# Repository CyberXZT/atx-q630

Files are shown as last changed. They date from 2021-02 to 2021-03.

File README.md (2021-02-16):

# ATX - Quadra 630 PSU Conversion Kit
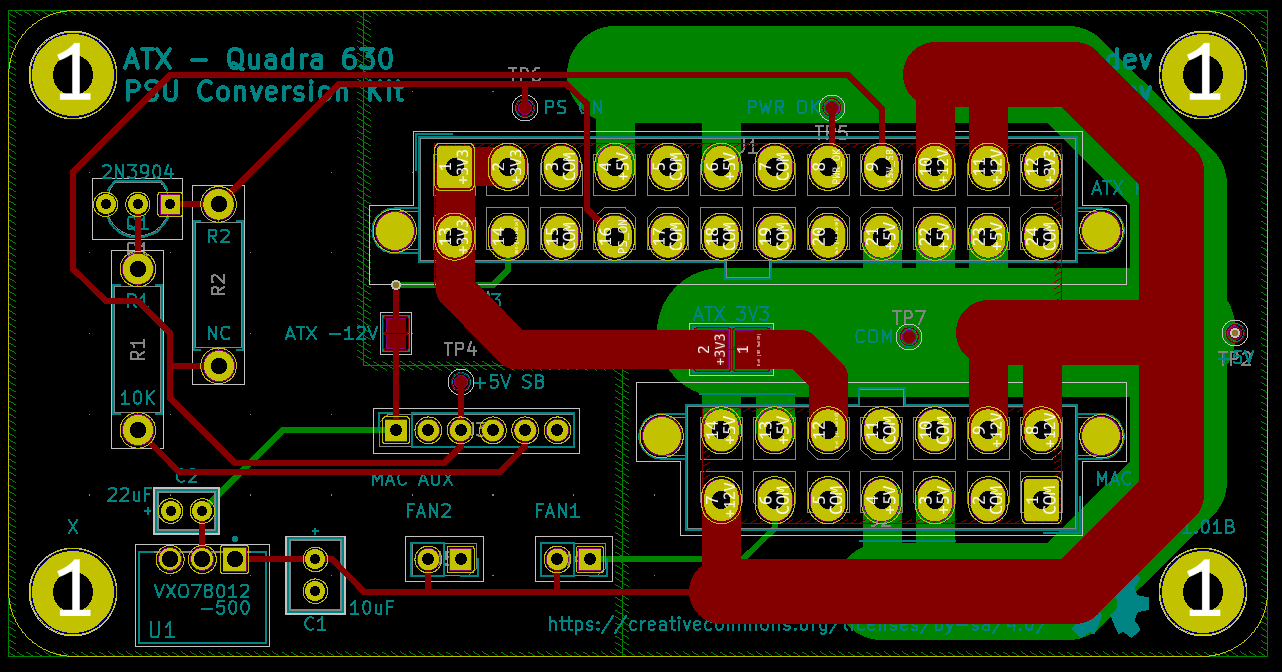
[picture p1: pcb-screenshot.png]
PCB Screenshot


This is an ATX/Quadra 630 PSU conversion PCB that I designed a while ago and
never got around to uploading.

[BOM](bom.csv)

**I am not an electrical engineer. I take no responsibility for any damage
these designs may cause. Use these designs with extreme caution.**

## Quick Notes
* R2 is unused.
* U1, C1, and C2 provide the -12V rail. If your PSU provides -12V, do not
populate these. Instead, bridge the "ATX -12V" jumper.
* 3.3V is not connected by default. The PSU in the original Quadra 630 PSU
uses this wire for ground. While the motherboards I tested did not actually
connect this wire, I have left it not connected by default. If you need 3.3V,
bridge the "ATX 3V3" jumper.
* I can't a good connector for the 6-pin "MAC-AUX" connector. The BOM
references the best fitting part although the smaller wall has to be cut in
order for the connector to fit. 
* PCB was designed with 2oz copper in mind.

## License and Copyright

Copyright &copy; Dean Winger 2021

This work is licensed under the Creative Commons
Attribution-ShareAlike 4.0 International License. To view a copy of
this license, visit http://creativecommons.org/licenses/by-sa/4.0/ or
send a letter to Creative Commons, PO Box 1866, Mountain View, CA
94042, USA.

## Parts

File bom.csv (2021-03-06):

Manufacturer Part Number | Manufacturer | Digi-Key Part Number | Customer Reference | Reference Designator | Packaging | Part Status | Quantity | Unit Price | Extended Price | Quantity Available | Mfg Std Lead Time | Description | RoHS Status | Lead Free Status | REACH Status
0015247141 | Molex | 23-0015247141-ND |  | J2 | Tray | Active | 1 | 3.18000 | $3.18 | 1019 | 18 Weeks | CONN RCPT 14POS 0.165 TIN PCB | ROHS3 Compliant | Lead free | REACH Unaffected
0460152403 | Molex | WM6198-ND |  | J1 | Tray | Active | 1 | 3.91000 | $3.91 | 734 | 7 Weeks | CONN HEADER VERT 24POS 4.2MM | ROHS3 Compliant | Lead free | REACH Unaffected
SWR25X-NRTC-S02-ST-BA | Sullins Connector Solutions | S9407-ND |  | J4,J5 | Bulk | Active | 2 | 0.12000 | $0.24 | 13375 | 5 Weeks | CONN HEADER VERT 2POS 2.54MM | ROHS3 Compliant | Lead free | REACH Unaffected
ROX05SJ10K | TE Connectivity Passive Product | A142728CT-ND |  | R1 | Cut Tape (CT) | Active | 1 | 0.18000 | $0.18 | 9324 | 18 Weeks | RES 1/2W SM M/OX 5% 10K | RoHS Compliant | Lead free | Not Available
FG14X5R1E226MRT06 | TDK Corporation | 445-173129-1-ND |  | C2 | Cut Tape (CT) | Active | 1 | 0.72000 | $0.72 | 2676 | 24 Weeks | CAP CER 22UF 25V X5R RADIAL | ROHS3 Compliant | Lead free | REACH Unaffected
FG11X7S1H106KRT06 | TDK Corporation | 445-180817-1-ND |  | C1 | Cut Tape (CT) | Active | 1 | 1.09000 | $1.09 | 2515 | 24 Weeks | CAP CER 10UF 50V X7S RADIAL | ROHS3 Compliant | Lead free | REACH Unaffected
VXO78012-500 | CUI Inc. | 102-4250-ND |  | U1 | Tray | Active | 1 | 2.36000 | $2.36 | 762 | 12 Weeks | DC DC CONVERTER 12V OR -12V 6W | RoHS Compliant | Lead free | Not Available
828548-6 | TE Connectivity AMP Connectors | A129104-ND |  | J3 | Bulk | Active | 1 | 0.47000 | $0.47 | 7923 | 21 Weeks | CONN HEADER VERT 6POS 2.54MM | RoHS Compliant | Lead free | Not Available
2N3904TFR | ON Semiconductor | 2N3904D26ZCT-ND |  | Q1 | Cut Tape (CT) | Active | 1 | 0.27000 | $0.27 | 0 | 26 Weeks | TRANS NPN 40V 200MA TO92-3 | ROHS3 Compliant | Lead free | REACH Unaffected

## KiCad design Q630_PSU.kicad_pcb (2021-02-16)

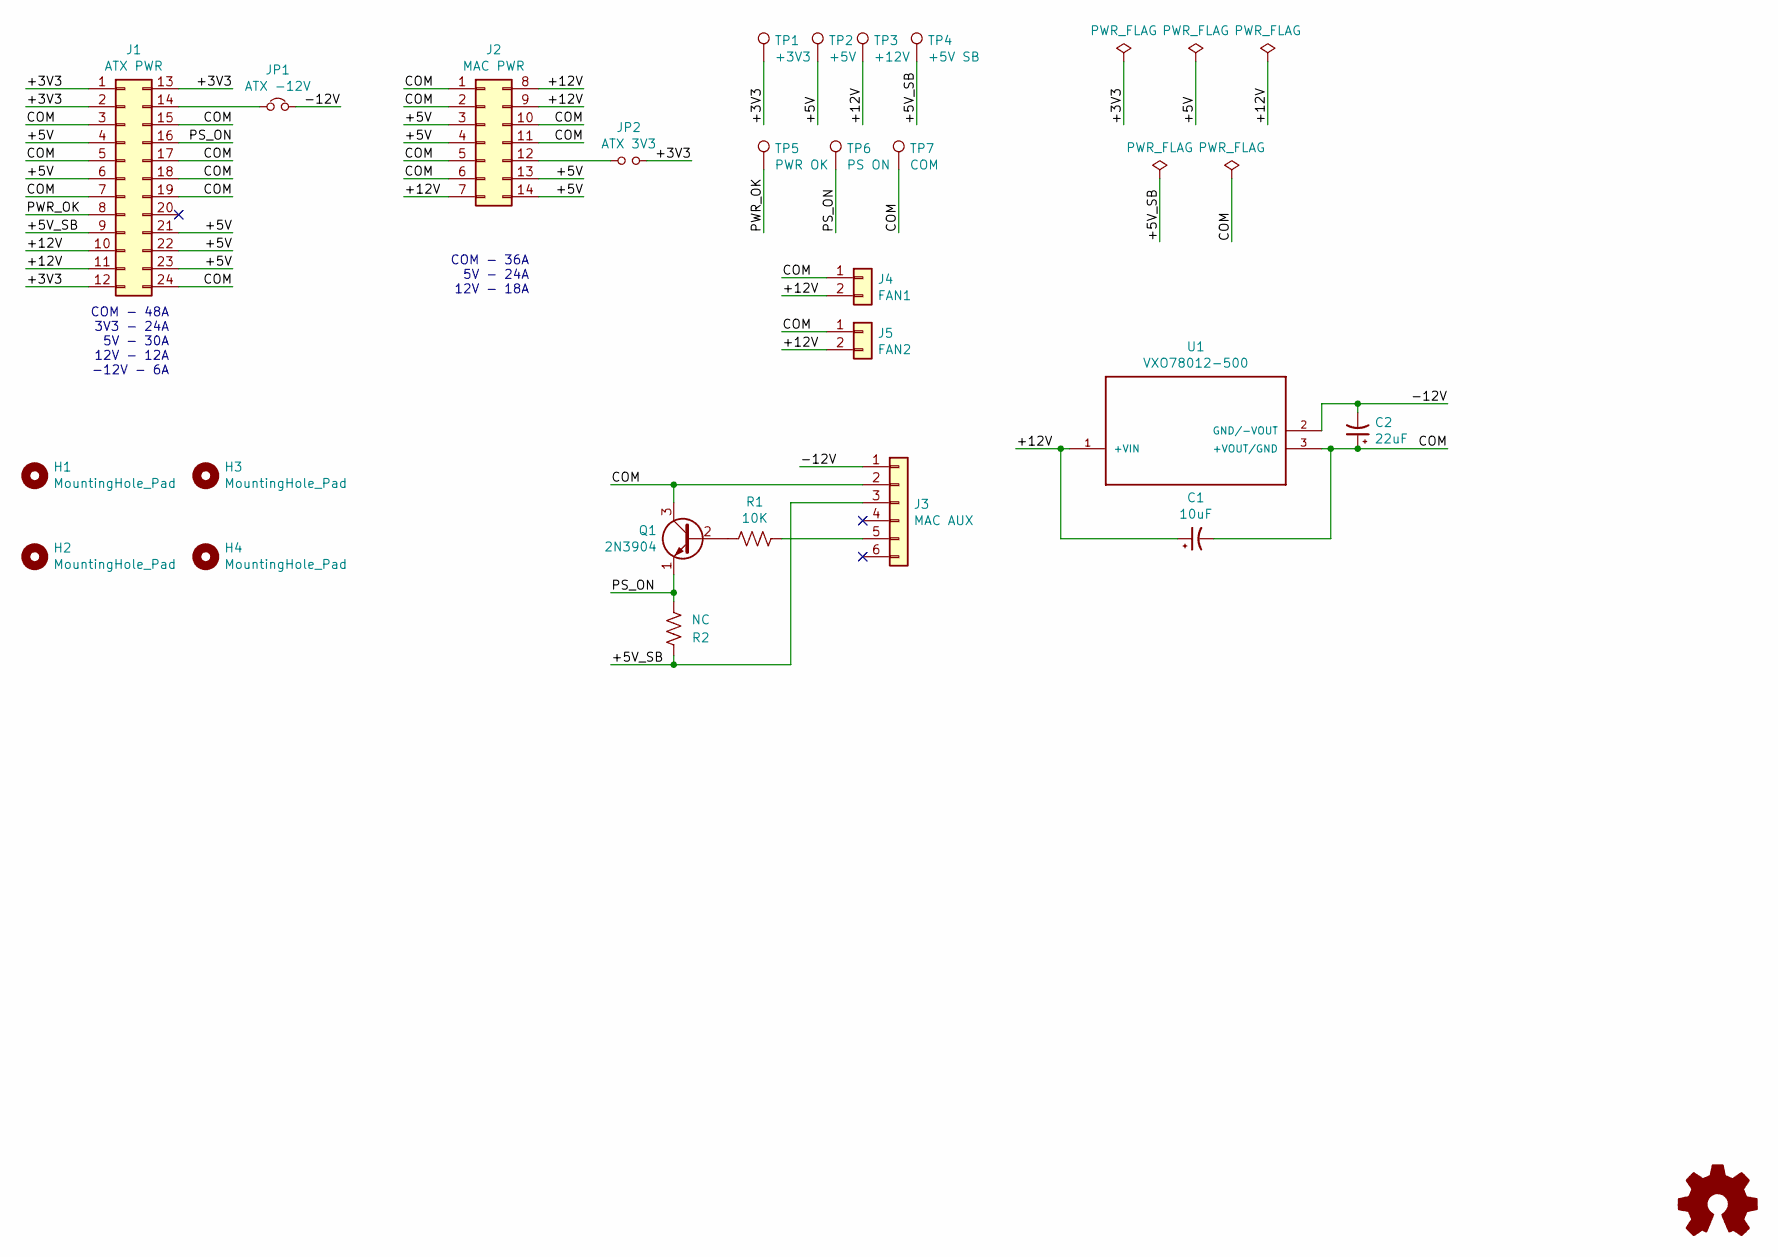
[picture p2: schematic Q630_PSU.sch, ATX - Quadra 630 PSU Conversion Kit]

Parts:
C1: 10uF; C1
C2: 22uF; C2
H1, H2, H3, H4: MountingHole_Pad; MountingHole_3.2mm_M3_Pad
J1: ATX PWR; Molex_Mini-Fit_Jr_5566-24A2_2x12_P4.20mm_Vertical
J2: MAC PWR; Molex_Mini-Fit_Jr_5566-14A2_2x07_P4.20mm_Vertical
J3: MAC AUX; PinSocket_1x06_P2.54mm_Vertical
J4: FAN1; PinSocket_1x02_P2.54mm_Vertical
J5: FAN2; PinSocket_1x02_P2.54mm_Vertical
JP1: ATX -12V; SolderJumper-2_P1.3mm_Open_Pad1.0x1.5mm
JP2: ATX 3V3; J2
Q1: 2N3904; TO-92_Inline_Wide
R1: 10K; R_Axial_DIN0411_L9.9mm_D3.6mm_P12.70mm_Horizontal
R2: NC; R_Axial_DIN0411_L9.9mm_D3.6mm_P12.70mm_Horizontal
TP1: +3V3; TestPoint_Pad_D1.0mm
TP2: +5V; TestPoint_Pad_D1.0mm
TP3: +12V; TestPoint_Pad_D1.0mm
TP4: +5V SB; TestPoint_Pad_D1.0mm
TP5: PWR OK; TestPoint_Pad_D1.0mm
TP6: PS ON; TestPoint_Pad_D1.0mm
TP7: COM; TestPoint_Pad_D1.0mm
U1: VXO78012-500; CONV_VXO78012-500

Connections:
/+3V3: J1.1, J1.2, J1.12, J1.13, JP2.2, TP1.1
/+5V: J1.4, J1.6, J1.21, J1.22, J1.23, J2.3, J2.4, J2.13, J2.14, TP2.1
/+5V_SB: J1.9, J3.3, R2.1, TP4.1
/+12V: C1.1, J1.10, J1.11, J2.7, J2.8, J2.9, J4.2, J5.2, TP3.1, U1.1 (+VIN)
/-12V: C2.2, J3.1, JP1.2, U1.2 (GND/-VOUT)
/COM: C1.2, C2.1, J1.3, J1.5, J1.7, J1.15, J1.17, J1.18, J1.19, J1.24, J2.1, J2.2, J2.5, J2.6, J2.10, J2.11, J3.2, J4.1, J5.1, Q1.3 (C), TP7.1, U1.3 (+VOUT/GND)
/PS_ON: J1.16, Q1.1 (E), R2.2, TP6.1
/PWR_OK: J1.8, TP5.1
unnamed: J1.14, JP1.1
unnamed: J2.12, JP2.1
unnamed: J3.5, R1.1
unnamed: Q1.2 (B), R1.2

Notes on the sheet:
COM - 48A 3V3 - 24A 5V - 30A 12V - 12A -12V - 6A
COM - 36A 5V - 24A 12V - 18A

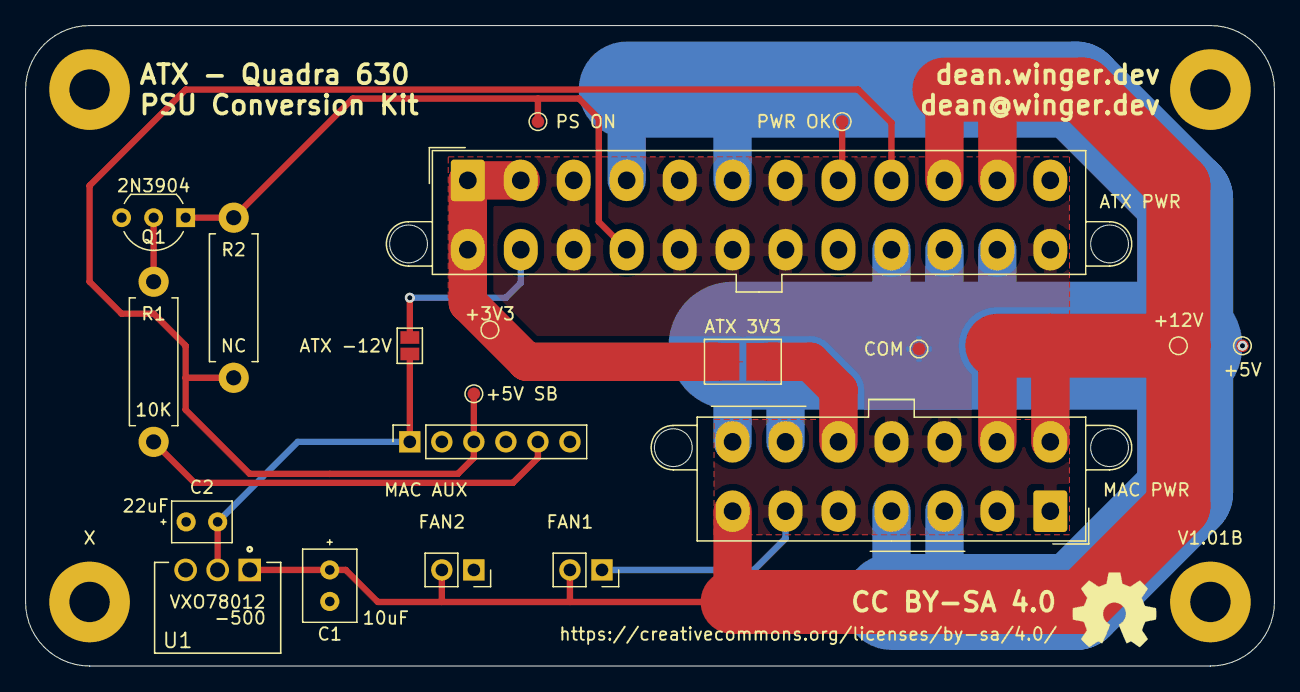
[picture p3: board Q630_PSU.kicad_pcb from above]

Board: 2 copper layers, 99.1 x 50.8 mm, 24 parts (0 on the bottom side), 12 nets.

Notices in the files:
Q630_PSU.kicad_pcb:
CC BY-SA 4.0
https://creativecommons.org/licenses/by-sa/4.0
